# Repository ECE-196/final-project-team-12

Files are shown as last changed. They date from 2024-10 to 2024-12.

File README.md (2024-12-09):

We developed a device to assist drivers with parking, specifically in compact spots. This will be done with a LiDAR sensor that will map a 2D birds eye view of obstacles in front and to the side of the car. This map will then be displayed on a screen for the driver to see and make judgements accordingly while parking. The device will assist the driver to measure the dimensions of a parking spot and help judge whether or not it is too compact to park in. 

This repository contains all the files and progression pictures/videos used to develop this product.

See our [Website](https://sites.google.com/ucsd.edu/team-12?usp=sharing) for more information

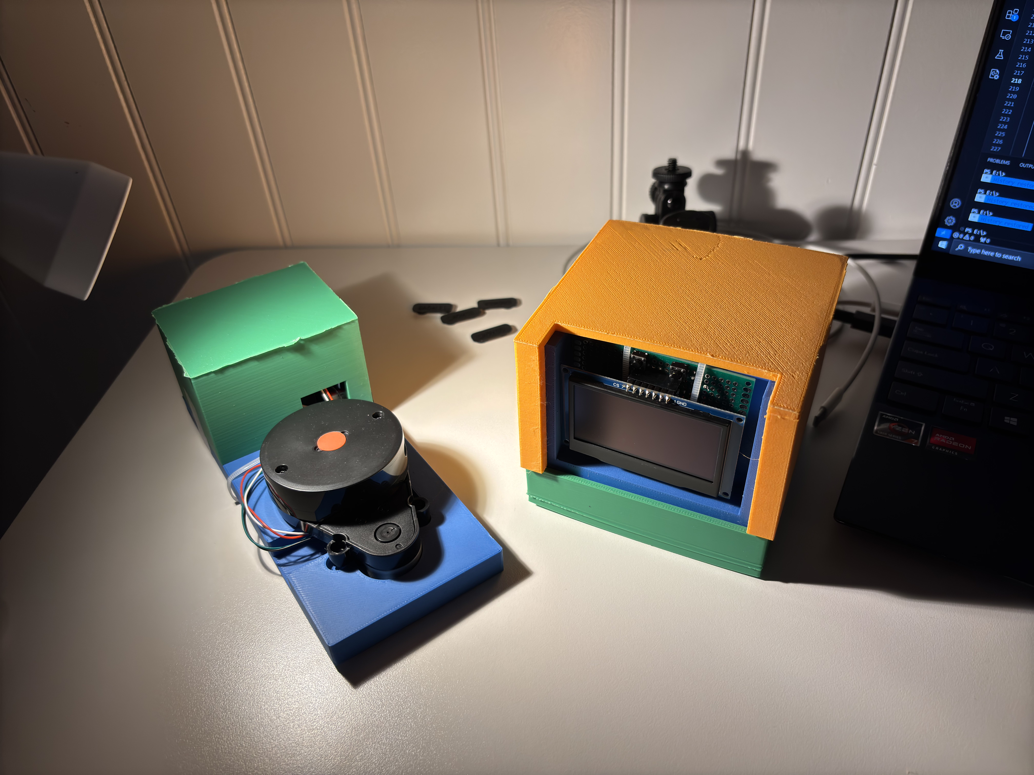
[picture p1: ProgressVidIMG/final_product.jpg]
final_product


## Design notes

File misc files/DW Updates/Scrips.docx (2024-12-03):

Did you ever find parking spaces are too small to comfortably park into? Do you consider yourself as a bad driver and would like some assistance to avoid hitting people’s car? Do you find it difficult to eye measure distances between obstacles and your car? Our parking assistance device is here to help you visualize obstacles near the front side of your car. Our product consists a lidar sensor scanning everything around your car front hood, displaying any obstacles on the screen. You will see how much space left your car has. No more accidentally hitting the car parked next to and having to worry about paying for the damage.

We designed our product to be as simple to install as possible. All you need to do is mount the sensor mount the sensor on your car using the suction cup (SPEECH PAUSE HERE A LITTLE), turn on the power switches, and set up the display. It just that easy! Our product allows for seamless wireless communication between devices, which means there's no need for cumbersome wires and hassles. Using LiDAR technology, it gives a 180 degree view of your car’s surroundings. This information is sent wirelessly to the screen. Surround cars, pillars, and other obstacles will now be detected and displayed to give you a better view of your surroundings. Gone are the days where parking is a hassle, gets your today for $499.99! Spot with our device, worry no more!

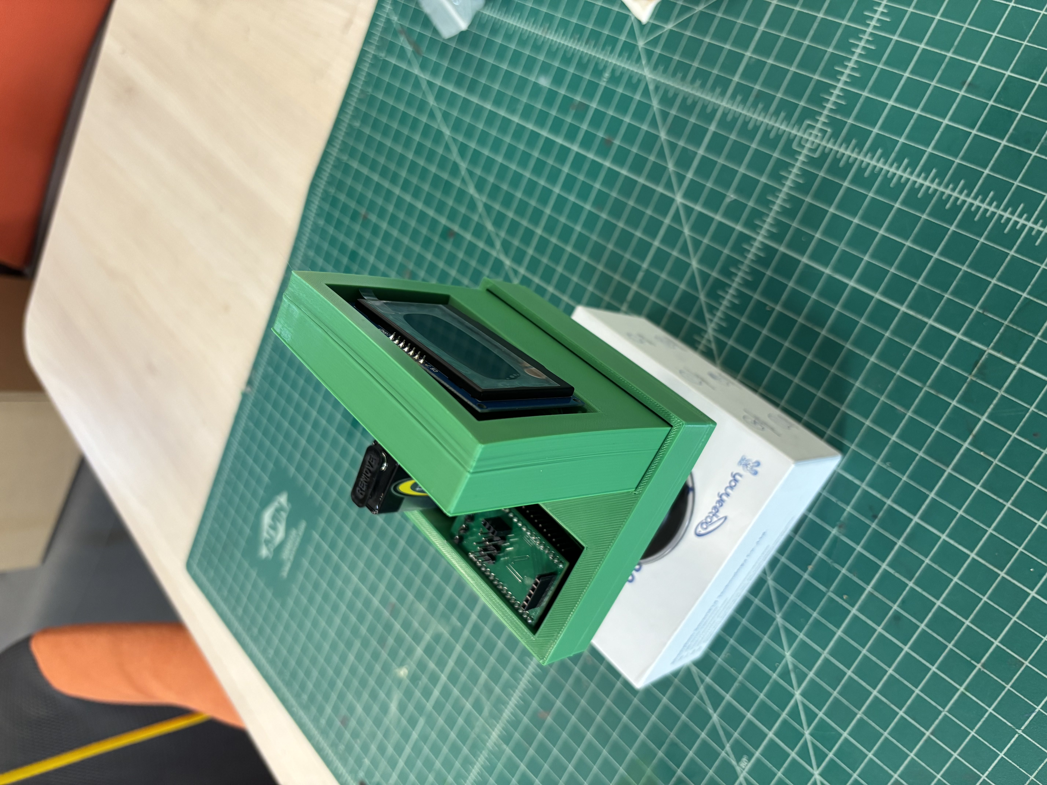
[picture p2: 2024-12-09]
ProgressVidIMG/prototype_screen_module.jpg

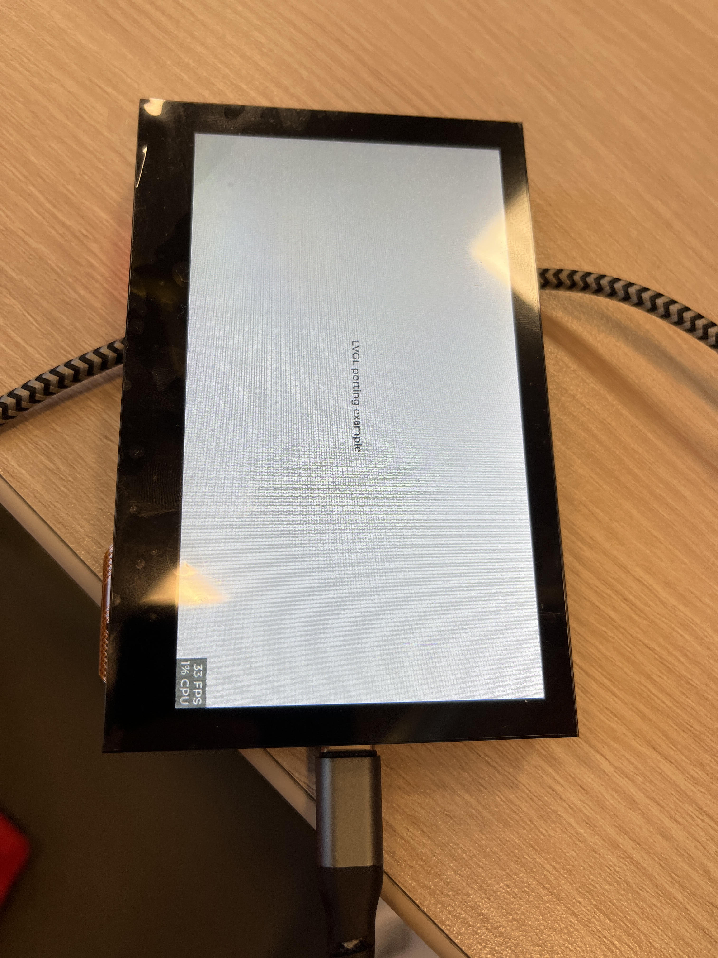
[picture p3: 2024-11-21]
misc files/DW Updates/ScreenDisplay.jpg

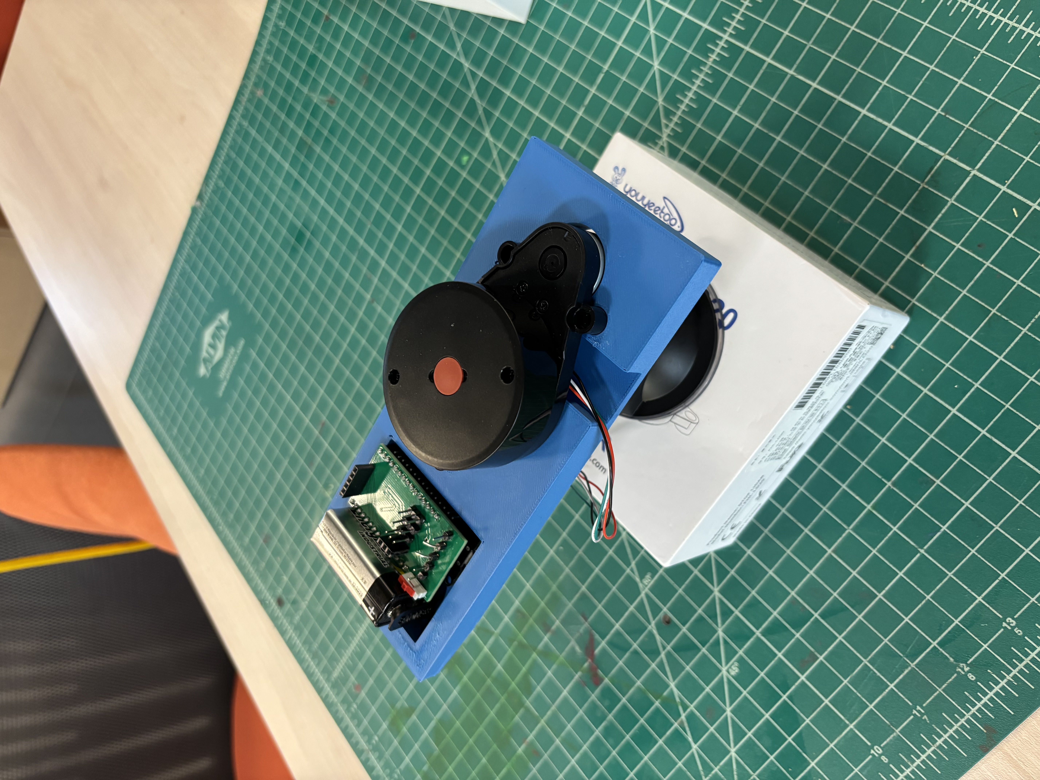
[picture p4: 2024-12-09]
ProgressVidIMG/prototype_sensor_module.jpg

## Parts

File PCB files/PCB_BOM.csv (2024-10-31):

Reference | Value | Datasheet | Footprint | Qty | DNP | Digikey part #
C1 | 22uF | ~ | Capacitor_SMD:C_0805_2012Metric | 1 |  | 1276-2909-1-ND
C2 | 100nF | ~ | Capacitor_SMD:C_0805_2012Metric | 1 |  | 1276-1782-1-ND
C3 | 10uF | ~ | Capacitor_SMD:C_0805_2012Metric | 1 |  | 1276-1096-1-ND
J1,J2 | Conn_01x15_Socket | ~ | Connector_PinHeader_2.54mm:PinHeader_1x15_P2.54mm_Vertical | 2 |  | S7013-ND
J3 | LiDAR_IN | ~ | Connector_PinHeader_2.54mm:PinHeader_1x03_P2.54mm_Vertical | 1 |  | S7001-ND
J4,J5,J6,J7,J12 | Conn_01x01_Pin | ~ | Connector_PinHeader_2.54mm:PinHeader_1x01_P2.54mm_Vertical | 5 |  | A26540-ND
J8,J9,J10 | Conn_01x03_Pin | ~ | Connector_PinHeader_2.54mm:PinHeader_1x03_P2.54mm_Vertical | 3 |  | 732-5316-ND
J11 | Conn_01x05_Pin | ~ | Connector_PinHeader_2.54mm:PinHeader_1x05_P2.54mm_Vertical | 1 |  | 732-5318-ND
L1 | 3.3uH | ~ | Inductor_SMD:L_0805_2012Metric | 1 |  | 2035-1251-1-ND
R1 | 52.3k | ~ | Resistor_SMD:R_0805_2012Metric | 1 |  | 541-52.3KCCT-ND
R2 | 10k | ~ | Resistor_SMD:R_0805_2012Metric | 1 |  | RR12P10.0KDCT-ND
SW1 | sw1 |  | 09.03201.02 | 1 |  | 1948-1086-ND
U1 | AP62150Z6-7 | AP62150Z6-7 | KiCADv6:SOT563_DIO | 1 |  | 31-AP62150Z6-7CT-ND

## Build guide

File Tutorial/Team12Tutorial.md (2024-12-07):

---
title: UART Communication
date: 12/6/2024
authors:
  - name: Cleavant Yang
  - name: Danny Wu
  - name: Aria Mottaghi
---
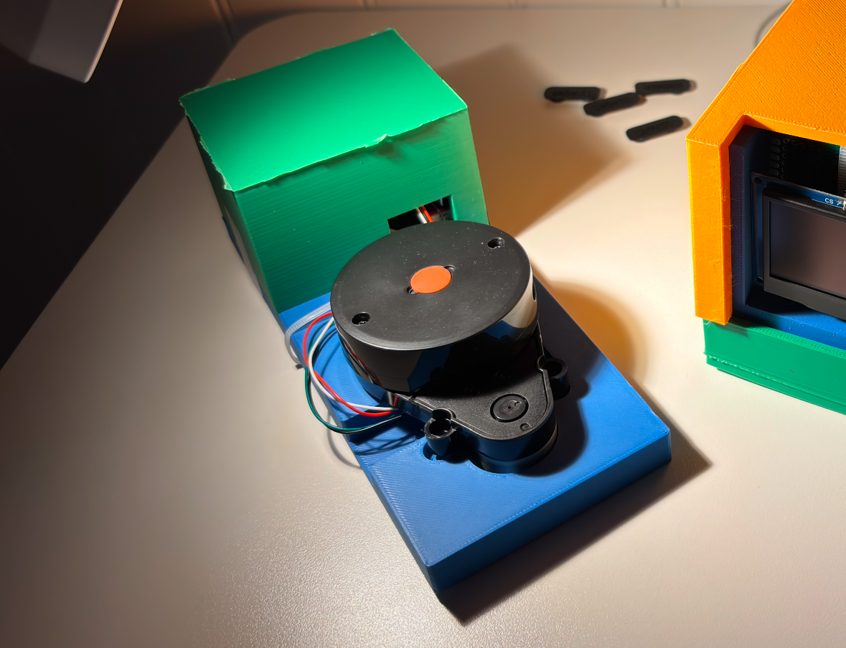
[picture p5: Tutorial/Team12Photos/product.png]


## Introduction

This tutorial will go over how to read incoming UART data from any device using CircuitPython. This is useful as a lot of devices send and receive information through this communication protocol. For the purposes of this tutorial, we will be receiving and decoding data from an [LD-14P LiDAR sensor][Lidar Link].  

### Learning Objectives

- UART Communication Protocol
- Circuit Python
- Datasheet Comprehension

## Background Information

Serial communication is a common method used in a lot of devices and electronics to send and receive information. Plenty of communication protocols exist such as I2C, SPI, and UART. Understanding serial communication, particularly UART (Universal Asynchronous Receiver-Transmitter), is essential for controlling, interfacing, and interacting with a wide range of devices, which is essential for projects that involve embedded systems. 

Pros:
- Overall simplicity
- Versatility

Cons:
- Slower speeds compared to other protocols
- Limited range as signal quality degrades over long distances

## Tools and Components Needed
- Computer or laptop that can run VSCode
- Visual Studio Code, download it [here][VSCode Link]
- Circuit Python, you can follow this instruction [here][Circuit Python Link], which is the same instruction for your VU Meter
- youyeetoo FHL-LD20 8 Meters 360 deg Lidar Sensor, you can find it [here][Lidar Link] and its datasheet [here][datasheetLink]
- ESP32 Devboard (The same one you made in class), details are found [here][devboardLink]
- USB-C cable
- Wires

## Get Started

### Serial Protocol

The UART communication protocol transmits data by sending bits one at a time, represented by high or low voltage levels, to the receiving device. Before communication begins, both devices agree on a baud rate, which determines the speed at which bits are transmitted per second.

Baudrates are going to vary widely across devices so it's important to make sure you are using the correct one. This information should always be outlined in the datasheet of the device you are working with (more on this below).

### Datasheet

Whenever working with electronic devices, it's essential to consult the accompanying datasheet, which provides detailed information on how the device works and how to configure it for your needs. The datasheet for the LiDAR sensor we're using can be found [here][datasheetLink].

In the case of the LiDAR sensor, the [datasheet][datasheetLink], when describing "transmission parameters," specifies a baud rate of 230400, meaning that 230,400 bits are transmitted per second.

### LiDAR Sensor

Since we're using a LiDAR sensor in this example, it's important to understand how it works. LiDAR operates by emitting a laser beam, which is invisible to the naked eye, towards nearby objects. The light reflects off these objects and is then received back by the LiDAR sensor. By knowing the speed of light and measuring the time it takes for the laser to travel to the object and return, the sensor can accurately calculate the distance to nearby objects. This distance data is then processed and continuously transmitted via the TX line as UART data.

This operation happens several thousands of times per second all while the internal sensors themselves are rotating in circles. This allows for a 2D top down mapping of all nearby objects

### ESP32

We will be using the [ESP32 devboard][devboardLink] you should have already made in class. This will be the microcontoller used to receive and process the UART data that's emitting from the LiDAR sensor.

### CircuitPython

I assume you have built the VU Meter using Circuit Python as [this instruction][Circuit Python Link], so you should have it installed and set up for the devboard you built earlier in class.

We will be using CircuitPython with this specific ESP32 chip as the preinstalled libraries are able to handle higher baudrates.

## Part 1: Wiring

### Introduction

We are first going to wire the LiDAR sensor to the devboard to interface with it.

### Objective

- Understanding the physical hardware of the sensor
- Learn how to read and comprehend information from a datasheet

### Background Information

The LiDAR sensor has four wires, each serving a different purpose. The datasheet specifies which wire corresponds to which function, and includes the following diagram for reference:

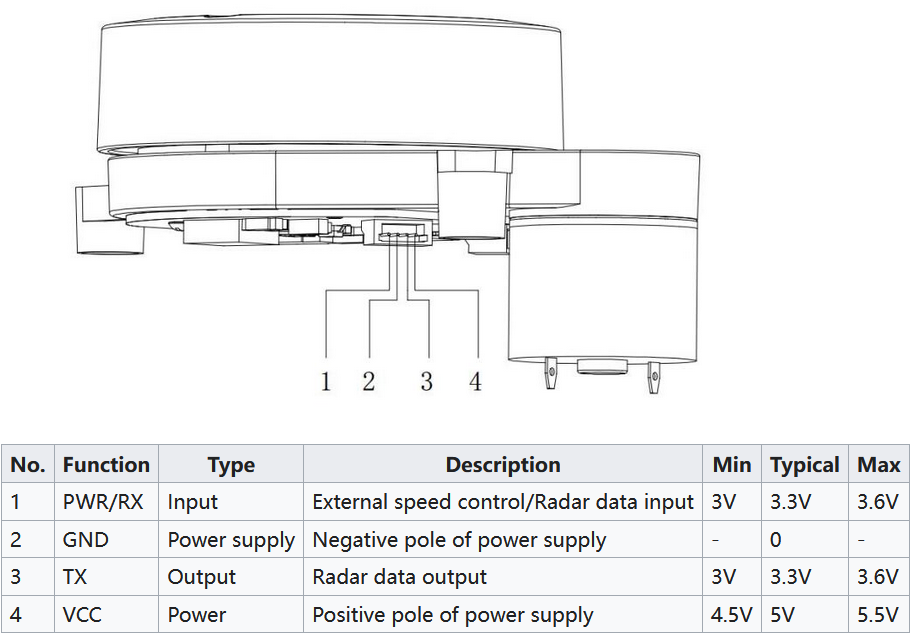
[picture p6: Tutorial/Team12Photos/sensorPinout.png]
pinoutPhoto


Because we are only interested in receiving UART data, further reading into the datasheet reveals that we can safely ignore the "PWR/RX" pin as there will be no need to send information to the sensor. We only care about pins 2, 3, and 4.

### Components

- LiDAR sensor
- 3 Wires
- Devboard

### Instructional

All the pins coming out of the sensor are going to be directly wired to the devboard. Referring back to the pinout image above, we need to power the VCC pin with 5V, tie the GND pin to the same ground as the devboard, and **connect the TX pin of the sensor to the RX0 of the devboard**. This wire will contain all the crucial data that will be read by the ESP32

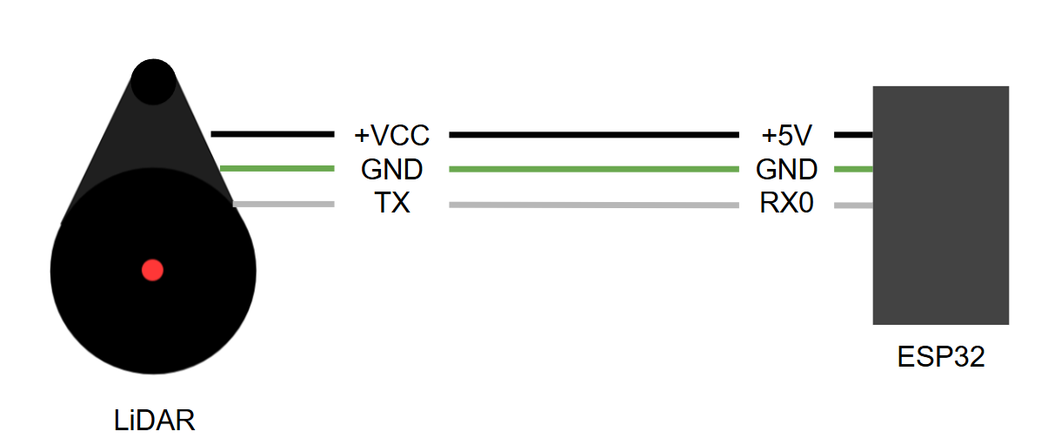
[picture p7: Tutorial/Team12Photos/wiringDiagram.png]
wiringDiagram


## Part 2: Code

### Introduction

We are now going to write code to interface with the LiDAR sensor in CircuitPython

### Objective

- Understand how to interface with UART data in CircuitPython
- Learn how to read and comprehend information from a datasheet

### Background Information

This section assumes you have a basic understanding of python syntax and that CircuitPython is already installed on your devboard.

### Components

- Devboard
- USB-C cable
- Computer/Laptop

### Instructional

Import the following libraries to interact with the devboard
```python
import board
import busio
```

Create a UART instance from the `busio.UART` class. Assign `baudrate` to 230400
```python
uart = busio.UART(board.TX, board.RX, baudrate=230400, timeout=0.1)
```

Print the incoming data coming from the UART instance. 
```python
while True:
    if uart.in_waiting > 0:
        data = uart.read()
        print(f"Received data: {data}")
```

This piece of code waits for data to be sent to the `RX0` pin and prints it to the console.

The LiDAR should be spinning and transmitting data automatically when powered. You should see something as such:
```
Received data: b'\x54'
Received data: b'\x2C'
Received data: b'\x68'
Received data: b'\x08'
.
.
.
```
We are now successfully receiving the UART LiDAR sensor data in [hexadecimal format][hexWiki]. To understand what any of it means, we have to yet again refer back to the datasheet. 

They specify the data structure of the packet they are sending out under "Data Packet Format"
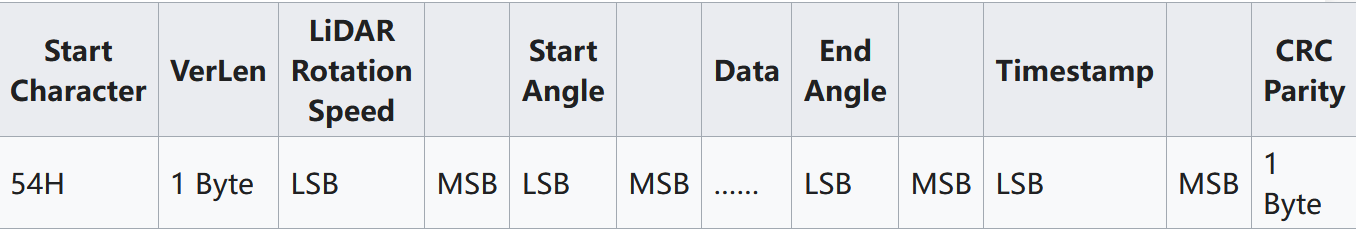
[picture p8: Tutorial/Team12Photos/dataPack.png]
dataPacket

Information on what MSB and LSB mean can be found [here][MLSB]

They also provide an example output and the corresponding decoded information:
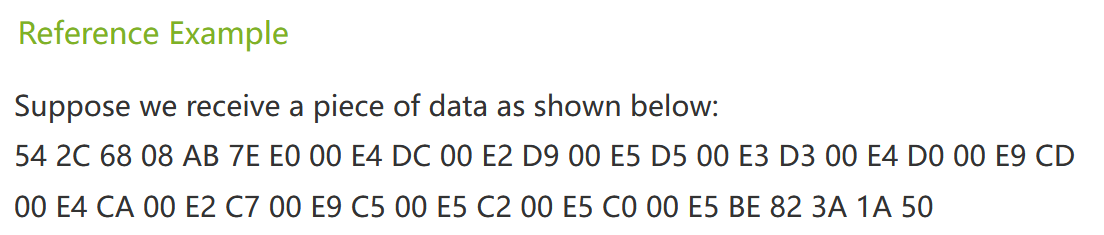
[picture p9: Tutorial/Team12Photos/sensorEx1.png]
inputExample1

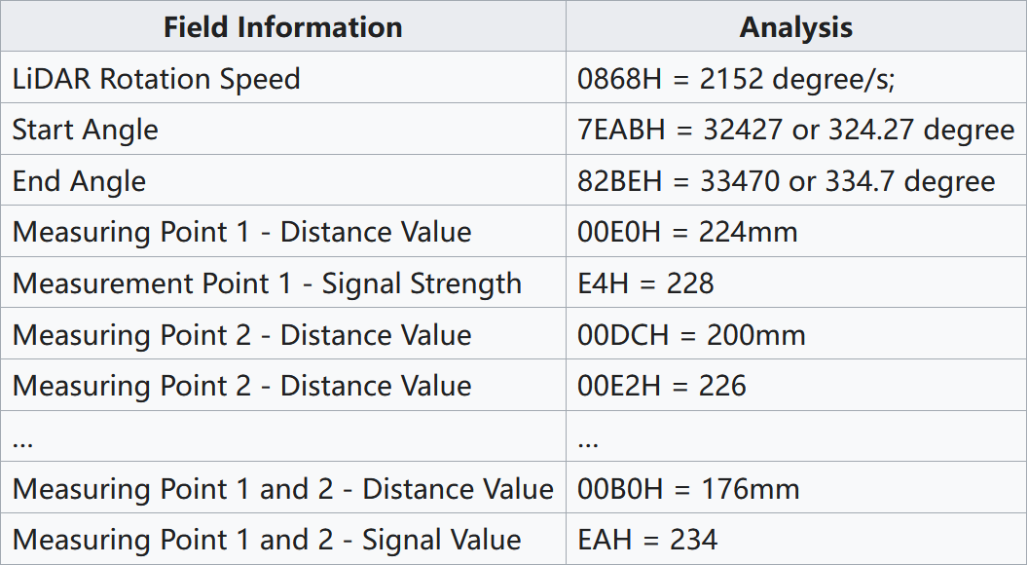
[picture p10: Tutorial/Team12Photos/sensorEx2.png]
inputExample2


## Example

### Introduction

We have successfully grabbed the UART data that was being transmitted by a sensor. Now we can convert the raw bytes that are being received to readable information of what the LiDAR is seeing.

### Example
The datasheet specifies that each set (or "packet") of data contains 47 bytes which all start with `0x54` indicating the beginning of the packet. We can first create a list that will hold all the information each packet contains
```python
packet_size = 47
packet = []
```

Now we want to take each byte we're receiving and place it into the list
```python
while True:
    if uart.in_waiting > 0:
        data = uart.read(uart.in_waiting)
        packet.extend(data)
```

We now implement another `while` loop which is responsible for processing the incoming data once we have enough bytes to form a full packet (in this case, 47 bytes).
```python
        while len(packet) >= packet_size:
            current_packet = packet[:packet_size]
            packet = packet[packet_size:]
```
The code slices the first 47 bytes from the `packet` list and stores them in `current_packet`. `current_packet` now holds one full packet that we will process. 

After extracting the first 47 bytes into `current_packet`, we update the `packet` list to remove those 47 bytes

This ensures that the remaining data in the `packet` list, if any, stays for the next loop cycle to be processed later.

Now we essentially "shift" what 47 bytes is contained in `current_packet` until the first byte is the start byte `0x54`
```python
            if current_packet[0] == 0x54:
                .
                .
                .
                # packet operations here

            else:
                packet = packet[1:]
```
Inside the conditional is code that executes with the guarantee that `current_packet` is a properly formatted data packet transmitted from the LiDAR

Refering back to this image:
dataPacket
We now know what information is contained in each index

We can do some basic print statements to verify that our code works as intended and that we're receiving the information correctly
```python
            if current_packet[0] == 0x54:
                for byte in current_packet:
                    print(f"{byte:02X}", end=" ")
                print()
            else:
                packet = packet[1:]
```

This is what was printed running the code above. Notice how similar it looks to the example given in the datasheet:
```
54 2C 74 08 B0 86 00 00 D4 00 00 D4 00 00 D4 00 00 D4 00 00 D4 00 00 D5 00 00 D5 00 00 49 00 00 5F 00 00 B0 00 00 D2 00 00 D4 02 89 1E 09 1F
54 2C 68 08 AB 7E E0 00 E4 DC 00 E2 D9 00 E5 D5 00 E3 D3 00 E4 D0 00 E9 CD 00 E4 CA 00 E2 C7 00 E9 C5 00 E5 C2 00 E5 C0 00 E5 BE 82 3A 1A 50
.
.
.
```

Given that we know each index's and the information it contains, here is an example function that prints legible information coming from the sensor:
```python
            if current_packet[0] == 0x54:
                print("radar speed:", end = " ")
                print(curPack[3]*256 + curPack[2])

                print("start angle:", end = " ")
                print(curPack[5]*256 + curPack[4])
                print("end angle:  ", end = " ")
                print(curPack[43]*256 + curPack[42])

                print("time:", end = " ")
                print(curPack[45]*256 + curPack[44])
            else:
                packet = packet[1:]
```

### Analysis

Explain how the example used your tutorial topic. Give in-depth analysis of each part and show your understanding of the tutorial topic

This example demonstrates how to decode each UART packet coming from a LiDAR sensor and, with the datasheet in hand, we can convert the bytes into legible information useful for interpreting the sensor's measurements. Using the data coming into the RX0 pin and knowing how it's formatted, we can extract meaningful data such as radar speed, angles, and other environmental details.

## Additional Resources

### Useful links

[Bit Significance][MLSB]

[Hexadecimal][hexWiki]

[LiDAR Sensor][Lidar Link]

[LiDAR Datasheet][datasheetLink]

[Lidar Link]: https://www.amazon.com/youyeetoo-FHL-LD20-Raspberry-Triangulated-Start-Stop/dp/B0C3CX17FN
[ESP32 Link]: https://www.amazon.com/dp/B08D5ZD528?ref=ppx_yo2ov_dt_b_fed_asin_title&th=1
[Screen Link]: https://www.amazon.com/dp/B0D7HN3XQ5?ref=ppx_yo2ov_dt_b_fed_asin_title
[Suction Cup Link]: https://www.amazon.com/ThtRht-Suction-Windshield-Camcorder-Recorder/dp/B0CPLV4B9F
[ESP-NOW Link]: https://www.espressif.com/en/solutions/low-power-solutions/esp-now
[Arduino IDE Link]: https://www.arduino.cc/en/software
[VSCode Link]: https://code.visualstudio.com/
[Circuit Python Link]: https://ece-196.github.io/docs/assignments/vu-meter/firmware/
[OLED Screen Link]: https://www.amazon.com/Teyleten-Robot-Display-SSD1309-Interface/dp/B09LND6QJ1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
[Library Link]: https://circuitpython.org/libraries
[SPI Wiki Link]: https://en.wikipedia.org/wiki/Serial_Peripheral_Interface
[datasheetLink]: https://www.waveshare.com/wiki/D200_LiDAR_Kit
[devboardLink]: https://ece-196.github.io/docs/assignments/dev-board/
[hexWiki]: https://en.wikipedia.org/wiki/Hexadecimal
[MLSB]: https://en.wikipedia.org/wiki/Bit_numbering

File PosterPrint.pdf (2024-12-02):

# Parking Assistant

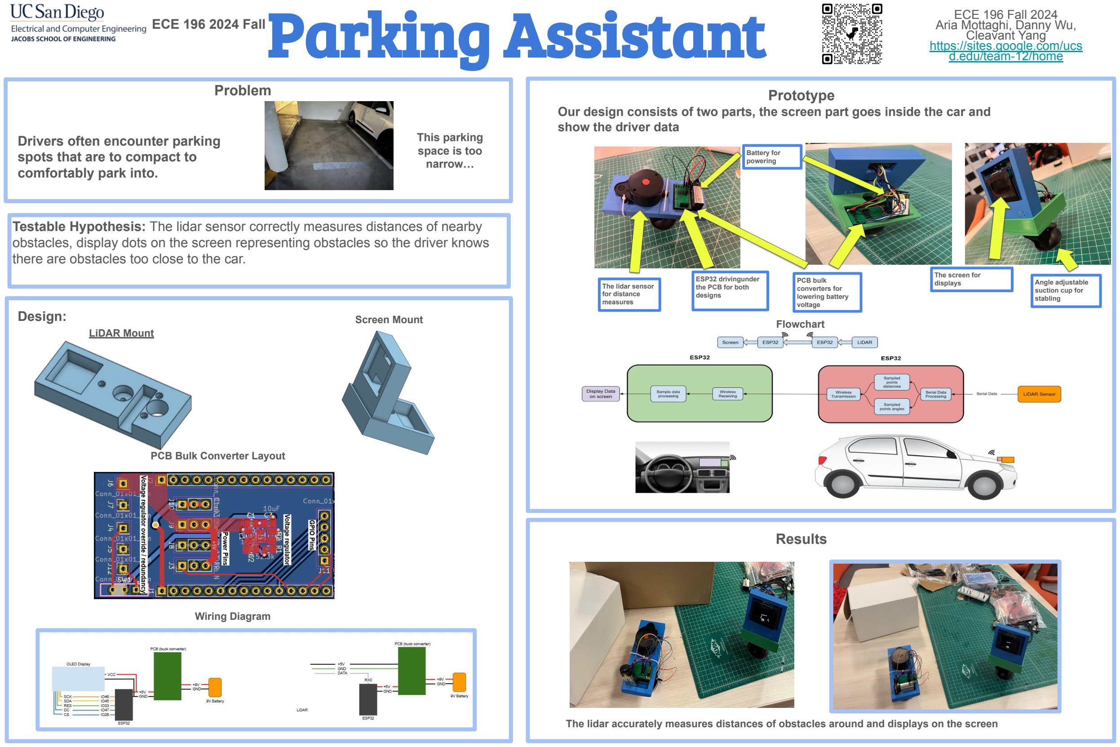
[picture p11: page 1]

ECE 196 Fall 2024
Aria Mottaghi, Danny Wu,
Cleavant Yang
https://sites.google.com/ucsd.edu/team-12/home (https://sites.google.com/ucsd.edu/team-12/home)

Drivers often encounter parking spots that are to compact to comfortably park into.

Testable Hypothesis: The lidar sensor correctly measures distances of nearby obstacles, display dots on the screen representing obstacles so the driver knows there are obstacles too close to the car.

Prototype

This parking
space is too
narrow…

Battery for
powering

LiDAR Mount

Angle adjustable
suction cup for
stabling

The screen for
displays

Our design consists of two parts, the screen part goes inside the car and show the driver data

PCB bulk
converters for
lowering battery
voltage
Design:

PCB Bulk Converter Layout

Wiring Diagram

Screen Mount

ECE 196 2024 Fall

The lidar sensor
for distance
measures

ESP32 drivingunder
the PCB for both
designs

Problem

Results

The lidar accurately measures distances of obstacles around and displays on the screen

Flowchart

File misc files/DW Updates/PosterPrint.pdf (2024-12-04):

# Parking Assistant

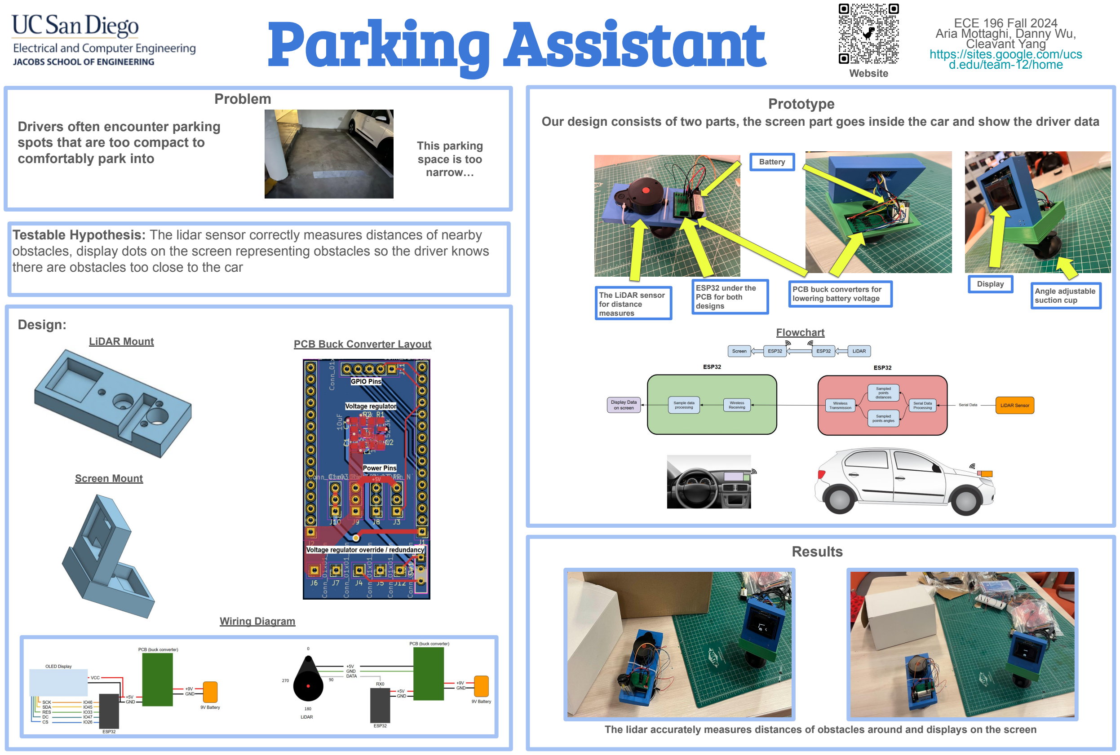
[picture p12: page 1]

ECE 196 Fall 2024
Aria Mottaghi, Danny Wu,
Cleavant Yang
https://sites.google.com/ucsd.edu/team-12/home (https://sites.google.com/ucsd.edu/team-12/home)

Drivers often encounter parking spots that are too compact to comfortably park into

Testable Hypothesis: The lidar sensor correctly measures distances of nearby obstacles, display dots on the screen representing obstacles so the driver knows there are obstacles too close to the car

Prototype

This parking
space is too
narrow…

Battery

LiDAR Mount

Angle adjustable
suction cup

Display

Our design consists of two parts, the screen part goes inside the car and show the driver data

PCB buck converters for
lowering battery voltage

Design:

PCB Buck Converter Layout

Wiring Diagram

Screen Mount

Website

The LiDAR sensor
for distance
measures

ESP32 under the
PCB for both
designs

Problem

Results

The lidar accurately measures distances of obstacles around and displays on the screen

Flowchart

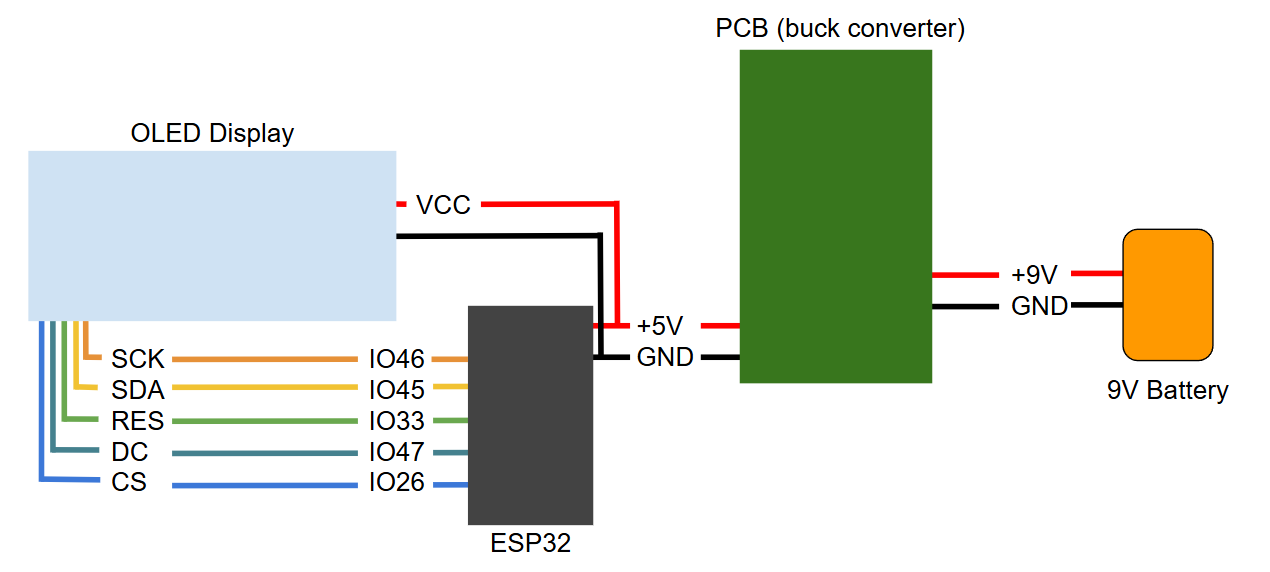
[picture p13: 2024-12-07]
ProgressVidIMG/wiringDiagram192p1.png

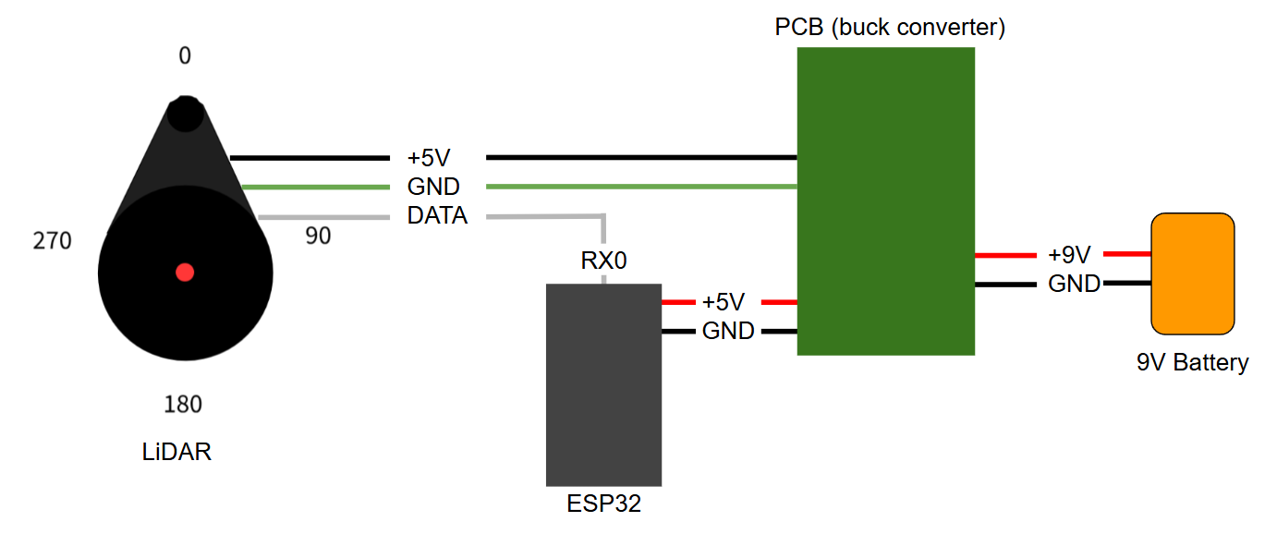
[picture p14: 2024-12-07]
ProgressVidIMG/wiringDiagram192p2.png

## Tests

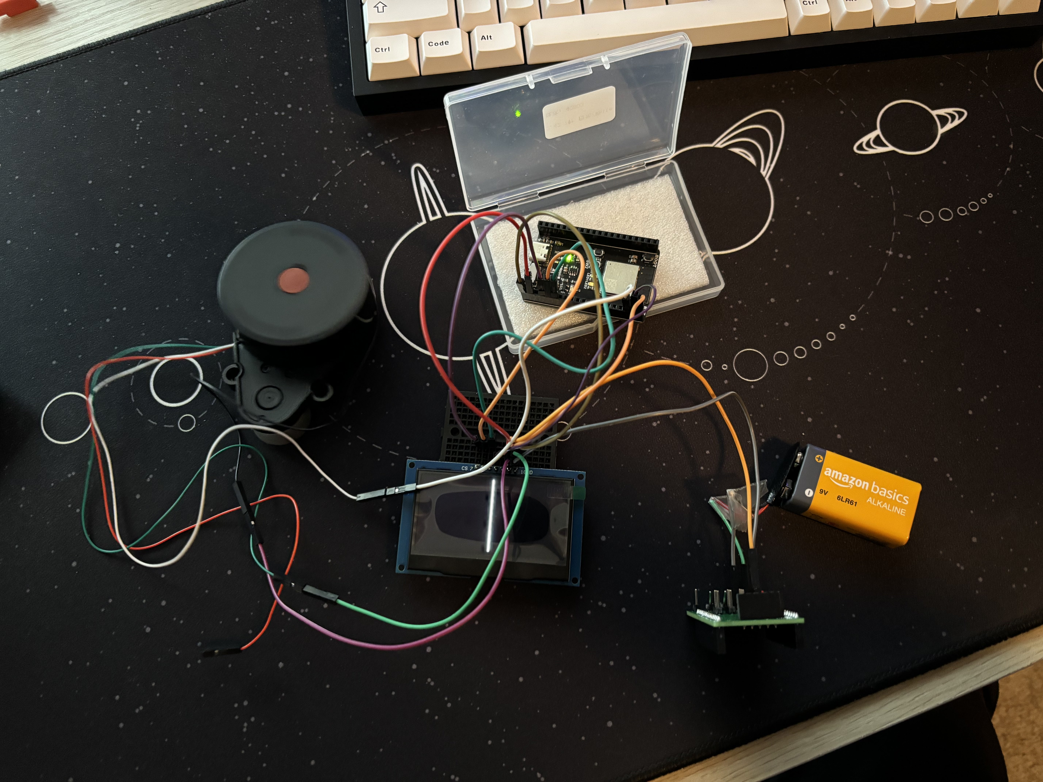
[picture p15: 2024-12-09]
ProgressVidIMG/first_system_integration_test.jpg

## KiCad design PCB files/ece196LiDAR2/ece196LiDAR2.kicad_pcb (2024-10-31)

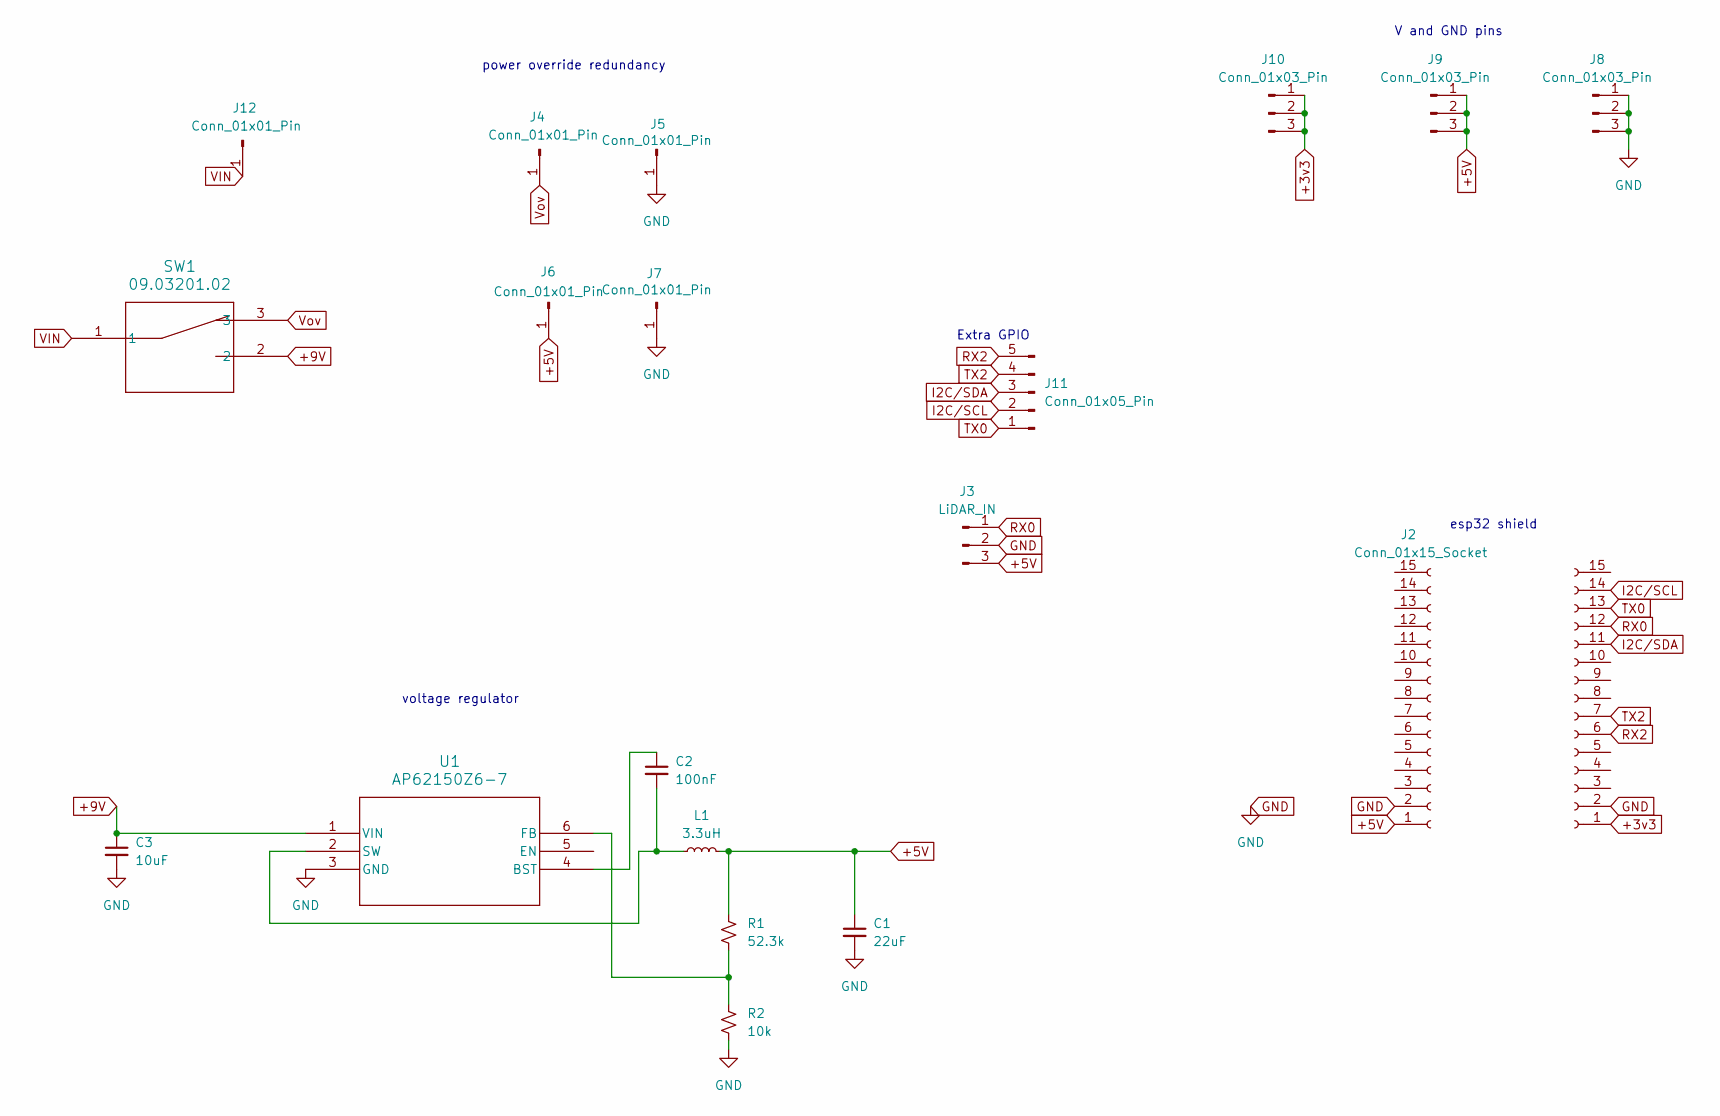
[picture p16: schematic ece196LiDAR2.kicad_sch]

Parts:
C1: 22uF; C_0805_2012Metric
C2: 100nF; C_0805_2012Metric
C3: 10uF; C_0805_2012Metric
J1, J2: Conn_01x15_Socket; PinHeader_1x15_P2.54mm_Vertical
J3: LiDAR_IN; PinHeader_1x03_P2.54mm_Vertical
J4, J5, J6, J7, J12: Conn_01x01_Pin; PinHeader_1x01_P2.54mm_Vertical
J8, J9, J10: Conn_01x03_Pin; PinHeader_1x03_P2.54mm_Vertical
J11: Conn_01x05_Pin; PinHeader_1x05_P2.54mm_Vertical
L1: 3.3uH; L_0805_2012Metric
R1: 52.3k; R_0805_2012Metric
R2: 10k; R_0805_2012Metric
SW1: 09.03201.02; 09.03201_EAO
U1: AP62150Z6-7; SOT563_DIO

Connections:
+3v3: J1.1, J10.1, J10.2, J10.3
+5V: C1.1, J2.1, J3.3, J6.1, J9.1, J9.2, J9.3, L1.2, R1.1
+9V: C3.1, SW1.2, U1.1 (VIN)
GND: C1.2, C3.2, J1.2, J2.2, J3.2, J5.1, J7.1, J8.1, J8.2, J8.3, R2.2, U1.3 (GND)
I2C/SCL: J1.14, J11.2
I2C/SDA: J1.11, J11.3
unnamed: C2.1, U1.4 (BST)
unnamed: R1.2, R2.1, U1.6 (FB)
unnamed: C2.2, L1.1, U1.2 (SW)
RX0: J1.12, J3.1
RX2: J1.6, J11.5
TX0: J1.13, J11.1
TX2: J1.7, J11.4
VIN: J12.1, SW1.1
Vov: J4.1, SW1.3

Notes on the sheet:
voltage regulator
Extra GPIO
V and GND pins
esp32 shield
power override redundancy

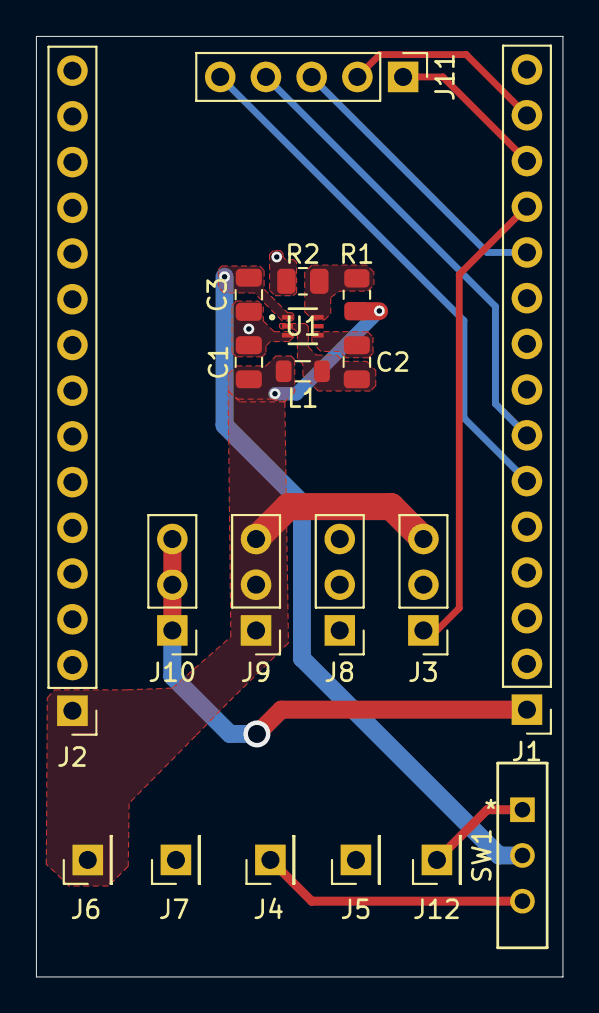
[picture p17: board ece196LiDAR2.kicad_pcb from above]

Board: 2 copper layers, 29.2 x 52.2 mm, 20 parts (0 on the bottom side), 15 nets.

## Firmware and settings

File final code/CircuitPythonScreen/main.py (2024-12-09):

import board
import time
import random
import displayio
import adafruit_displayio_ssd1306
import busio
import espnow #type: ignore
import math
import json
from digitalio import DigitalInOut, Direction

'''
displayio.release_displays() #release pins

WIDTH = 128
HEIGHT = 64
BORDER = 5

# Set up the SPI or I2C connection (depending on your setup)
cs = board.IO26 #IO26, chip select
dc = board.IO47 #IO47, data address
reset = board.IO33 #IO33, reset pin
spi = busio.SPI(board.IO46, MOSI=board.IO45) #initialize bus
display_bus = displayio.FourWire(spi, command=dc, chip_select=cs,
                                 reset=reset, baudrate=1000000)
#SDA IO45, MOSI
#SCK IO46, clock

# Create the display object
display = adafruit_displayio_ssd1306.SSD1306(display_bus, width=WIDTH, height=HEIGHT)

splash = displayio.Group() #Manage a group of sprites and groups and how they are inter-related.
display.show(splash)

# Create a bitmap where we can draw pixels
bitmap = displayio.Bitmap(128, 64, 2)  # 128x64 pixels, 2 colors (black and white)
palette = displayio.Palette(2)
palette[0] = 0x000000  # Black
palette[1] = 0xFFFFFF  # White

# Create a TileGrid to hold the bitmap
tile_grid = displayio.TileGrid(bitmap, pixel_shader=palette)

# Create a Group and add the TileGrid to it
group = displayio.Group()
group.append(tile_grid) # append() adds elements to splash and make them visible

# Show the group on the display
display.show(group)

# Function to draw a single pixel
def draw_pixel(x, y, color):
    if 0 <= x < 128 and 0 <= y < 64:  # Make sure the pixel is within bounds
        bitmap[x, y] = color
        time.sleep(0.1)
        #bitmap[x, y] = 0 #turn off pixel

def turnoff_pixel(x, y, color):
    if 0 <= x < 128 and 0 <= y < 64:  # Make sure the pixel is within bounds
        bitmap[x, y] = 0
        # time.sleep(0.2)
        # bitmap[x, y] = 0 #turn off pixel

# Draw some test pixels
#draw_pixel(random.randint(0,128), random.randint(0,64), 1)  # Draw a white pixel at (10, 10)

# To update display, we don’t need anything else because displayio handles it automatically
while True:
    for x in range(128):
        draw_pixel(x, 0, 1)  # Draw a white pixel at (10, 10)
        #time.sleep(0.1)
    for x in range(128):
        turnoff_pixel(x,0,0)
    #draw_pixel(random.randint(0,128), random.randint(0,64), 1)  # Draw a white pixel at (10, 10)
    time.sleep(0.1)
'''

# =============================================================================================================================
# display initialization 

refreshRate = 3
scaleDown = 10 # variable to adjust to zoom in or out on the screen
scdl = 10
scdm = 25
scdh = 100
leftButton = DigitalInOut(board.IO1)
leftButton.direction = Direction.INPUT
rightButton = DigitalInOut(board.IO2)
rightButton.direction = Direction.INPUT
pLeftButton = False
pRightButton = False

displayio.release_displays() #release pins

# Set up the SPI or I2C connection (depending on your setup)
cs = board.IO26 #IO26
dc = board.IO47 #IO47
reset = board.IO33 #IO33
spi = busio.SPI(board.IO46, MOSI=board.IO45) #initialize bus
display_bus = displayio.FourWire(spi, command=dc, chip_select=cs, reset=reset, baudrate=230400) # 1000000
#SDA IO45
#SCK IO46

# Create the display object
display = adafruit_displayio_ssd1306.SSD1306(display_bus, width=128, height=64)

splash = displayio.Group() #Manage a group of sprites and groups and how they are inter-related.
display.show(splash)

# Create a bitmap where we can draw pixels
bitmap = displayio.Bitmap(128, 64, 2)  # 128x64 pixels, 2 colors (black and white)
palette = displayio.Palette(2)
palette[0] = 0x000000  # Black
palette[1] = 0xFFFFFF  # White

# Create a TileGrid to hold the bitmap
tile_grid = displayio.TileGrid(bitmap, pixel_shader=palette)

# Create a Group and add the TileGrid to it
group = displayio.Group()
group.append(tile_grid) # append() adds elements to splash and make them visible

# Show the group on the display 
display.show(group)

def drawPixel(x, y, z):
    if 0 <= x < 128 and 0 <= y < 64:  # will only draw pixels within bounds
        if bitmap[x,y] != int(z):
            bitmap[x, y] = int(z)

def drawCar():
    global scaleDown
    carPixels = set()
    height = 58 # y coord 

# real distance in mm / scaleDown = pixelPlot
# 8000/10 = 800 (too far at this scaleDown value)
# 8000/x = 440 (find x for it to be at the midpoint) (x = 18.18)
# 8000/100 = 80 ( < 127, will fit on screen)

# 2000/10 = 200
# 2000/18.18 = 110
# 2000/100 = 20

# 1000/10 = 100 
# 1000/18.18 = 55
# 1000/100 = 10 

    if scaleDown == scdh:
        for i in range(57,69): # bumper width
            carPixels.add((i,height)) # bumper height
        for i in range(height + 1,64): # left side height
            carPixels.add((56,i)) # left side x coord
        for i in range(height + 1,64): # right side height
            carPixels.add((69,i)) # right side x coord

    elif scaleDown == scdm:
        # 28
        carPixels.add((28,height+5))
        carPixels.add((29,height+4))
        carPixels.add((29,height+3))
        for i in range(30,32):
            carPixels.add((i,height+2)) 
        for i in range(32,50):
            carPixels.add((i,height+1)) 
        for i in range(50,77): # bumper width
            carPixels.add((i,height)) # bumper height
        for i in range(77,95): # bumper width
            carPixels.add((i,height+1)) # bumper height
        for i in range(95,97):
            carPixels.add((i,height+2))
        carPixels.add((97,height+3))
        carPixels.add((97,height+4))
        carPixels.add((98,height+5))
        
    elif scaleDown == scdl:
        for i in range(57,69): # bumper width
            carPixels.add((i,height)) # bumper height
        for i in range(height + 1,64): # left side height
            carPixels.add((56,i)) # left side x coord
        for i in range(height + 1,64): # right side height
            carPixels.add((69,i)) # right side x coord
        for i in range(59,67):
            carPixels.add((i,63))

        # carPixels.add((63,height+5))
        # 98

    for x in carPixels:
        bitmap[x] = 1
drawCar()
# 0 - 57 is the y range because the car bumper goes to y = 58 - 63

def clearScreen():
    global timeSinceReset
    bitmap.fill(0)
    drawCar()
    timeSinceReset = time.monotonic()

timeSinceReset = time.monotonic()

# Function to update plot based on angle and distance
def updatePlot(i):
    curTime = time.monotonic()
    global timeSinceReset, scaleDown
    
    if (27000 <= i[1] <= 36000) or (0 <= i[1] <= 9000):
        # Get the angle and distance from the data
        angle = ( 9000 - i[1]) / 100.0  # Convert angle from scaled value (e.g., 9000 = 90Â°) to degrees
        distance = i[0]  # Distance value
        
        # Convert angle to radians (since math functions use radians)
        angle_radians = math.radians(angle)

        # Center of the screen
        xMid = 63
        yMid = 59  # center the LiDAR to the car on the screen

        # polar to cartesian conversion
        x = xMid + int(distance * math.cos(angle_radians) / scaleDown)
        y = yMid - int(distance * math.sin(angle_radians) / scaleDown)  # Invert Y-axis



        drawPixel(x,y,1)  # Run the expression for each (x, y) pair
        if (curTime - timeSinceReset >= refreshRate):
            clearScreen()
#-------------------------------------------------------------------------
#Receiver Wireless Code Start
#import espnow, time

e = espnow.ESPNow()
packets = []
print("Initializing ESP-NOW Receiver...")
while True:
    # Read any incoming message
    if e:
        message = e.read()
        #print(type(message))
        #print("Received message:", message.msg)
        decoded_data = message.msg.decode('utf-8')  # Decode from bytes to string
        original_element = json.loads(decoded_data)  # Deserialize the JSON string back to the original element
        if isinstance(original_element,list) and original_element[0] != 0 and original_element[1] != 0:
            updatePlot(original_element)


        # more efficient but too volatile
        # # print(original_element)
        # if isinstance(original_element,str) and len(original_element) == 120:
        #     # print(original_element) 
        #     for i in range(0, len(original_element), 10):
        #         num1 = int(original_element[i:i+5])
        #         num2 = int(original_element[i+5:i+10])
        #         updatePlot([num1, num2])


    # Add a small delay to avoid overwhelming the loop
    time.sleep(0.001)  # Adjust sleep time as needed
    if leftButton.value == False and pLeftButton == True: # scaleDown go up
        if scaleDown == scdl:
            scaleDown = scdm
        elif scaleDown == scdm:
            scaleDown = scdh
        clearScreen()
    if rightButton.value == False and pRightButton == True: # scaleDown go down 
        if scaleDown == scdm:
            scaleDown = scdl
        elif scaleDown == scdh:
            scaleDown = scdm
        clearScreen()
    pLeftButton = leftButton.value
    pRightButton = rightButton.value

#Receiver Wireless Code Ends
#-------------------------------------------------------------------------

'''
import board
import time
import random
import displayio
import adafruit_displayio_ssd1306
import busio
import espnow #type: ignore
import math
import json
from digitalio import DigitalInOut, Direction

# =============================================================================================================================
# display initialization 

refreshRate = 3
scaleDown = 10 # variable to adjust to zoom in or out on the screen
scdl = 10
scdm = 25
scdh = 100
leftButton = DigitalInOut(board.D2)
leftButton.direction = Direction.INPUT
rightButton = DigitalInOut(board.D4)
rightButton.direction = Direction.INPUT
pLeftButton = False
pRightButton = False

displayio.release_displays() #release pins

# Set up the SPI or I2C connection (depending on your setup)
cs = board.D26 #IO26
dc = board.D27 #IO47
reset = board.D14 #IO33
spi = busio.SPI(board.D13, MOSI=board.D12) #initialize bus
display_bus = displayio.FourWire(spi, command=dc, chip_select=cs, reset=reset, baudrate=230400) # 1000000
#SDA IO45
#SCK IO46

# Create the display object
display = adafruit_displayio_ssd1306.SSD1306(display_bus, width=128, height=64)

splash = displayio.Group() #Manage a group of sprites and groups and how they are inter-related.
display.show(splash)

# Create a bitmap where we can draw pixels
bitmap = displayio.Bitmap(128, 64, 2)  # 128x64 pixels, 2 colors (black and white)
palette = displayio.Palette(2)
palette[0] = 0x000000  # Black
palette[1] = 0xFFFFFF  # White

# Create a TileGrid to hold the bitmap
tile_grid = displayio.TileGrid(bitmap, pixel_shader=palette)

# Create a Group and add the TileGrid to it
group = displayio.Group()
group.append(tile_grid) # append() adds elements to splash and make them visible

# Show the group on the display 
display.show(group)

def drawPixel(x, y, z):
    if 0 <= x < 128 and 0 <= y < 64:  # will only draw pixels within bounds
        if bitmap[x,y] != int(z):
            bitmap[x, y] = int(z)

def drawCar():
    global scaleDown
    carPixels = set()
    height = 58 # y coord 

# real distance in mm / scaleDown = pixelPlot
# 8000/10 = 800 (too far at this scaleDown value)
# 8000/x = 440 (find x for it to be at the midpoint) (x = 18.18)
# 8000/100 = 80 ( < 127, will fit on screen)

# 2000/10 = 200
# 2000/18.18 = 110
# 2000/100 = 20

# 1000/10 = 100 
# 1000/18.18 = 55
# 1000/100 = 10 

    if scaleDown == scdh:
        for i in range(57,69): # bumper width
            carPixels.add((i,height)) # bumper height
        for i in range(height + 1,64): # left side height
            carPixels.add((56,i)) # left side x coord
        for i in range(height + 1,64): # right side height
            carPixels.add((69,i)) # right side x coord

    elif scaleDown == scdm:
        # 28
        carPixels.add((28,height+5))
        carPixels.add((29,height+4))
        carPixels.add((29,height+3))
        for i in range(30,32):
            carPixels.add((i,height+2)) 
        for i in range(32,50):
            carPixels.add((i,height+1)) 
        for i in range(50,77): # bumper width
            carPixels.add((i,height)) # bumper height
        for i in range(77,95): # bumper width
            carPixels.add((i,height+1)) # bumper height
        for i in range(95,97):
            carPixels.add((i,height+2))
        carPixels.add((97,height+3))
        carPixels.add((97,height+4))
        carPixels.add((98,height+5))
        
    elif scaleDown == scdl:
        for i in range(57,69): # bumper width
            carPixels.add((i,height)) # bumper height
        for i in range(height + 1,64): # left side height
            carPixels.add((56,i)) # left side x coord
        for i in range(height + 1,64): # right side height
            carPixels.add((69,i)) # right side x coord
        for i in range(59,67):
            carPixels.add((i,63))

        # carPixels.add((63,height+5))
        # 98

    for x in carPixels:
        bitmap[x] = 1
drawCar()
# 0 - 57 is the y range because the car bumper goes to y = 58 - 63

def clearScreen():
    global timeSinceReset
    bitmap.fill(0)
    drawCar()
    timeSinceReset = time.monotonic()

timeSinceReset = time.monotonic()

# Function to update plot based on angle and distance
def updatePlot(i):
    curTime = time.monotonic()
    global timeSinceReset, scaleDown
    
    if (27000 <= i[1] <= 36000) or (0 <= i[1] <= 9000):
        # Get the angle and distance from the data
        angle = ( 9000 - i[1]) / 100.0  # Convert angle from scaled value (e.g., 9000 = 90Â°) to degrees
        distance = i[0]  # Distance value
        
        # Convert angle to radians (since math functions use radians)
        angle_radians = math.radians(angle)

        # Center of the screen
        xMid = 63
        yMid = 59  # center the LiDAR to the car on the screen

        # polar to cartesian conversion
        x = xMid + int(distance * math.cos(angle_radians) / scaleDown)
        y = yMid - int(distance * math.sin(angle_radians) / scaleDown)  # Invert Y-axis



        drawPixel(x,y,1)  # Run the expression for each (x, y) pair
        if (curTime - timeSinceReset >= refreshRate):
            clearScreen()
#-------------------------------------------------------------------------
#Receiver Wireless Code Start
#import espnow, time

e = espnow.ESPNow()
packets = []
print("Initializing ESP-NOW Receiver...")
while True:
    # Read any incoming message
    if e:
        message = e.read()
        #print(type(message))
        #print("Received message:", message.msg)
        decoded_data = message.msg.decode('utf-8')  # Decode from bytes to string
        original_element = json.loads(decoded_data)  # Deserialize the JSON string back to the original element
        if isinstance(original_element,list) and original_element[0] != 0 and original_element[1] != 0:
            updatePlot(original_element)


        # more efficient but too volatile
        # # print(original_element)
        # if isinstance(original_element,str) and len(original_element) == 120:
        #     # print(original_element) 
        #     for i in range(0, len(original_element), 10):
        #         num1 = int(original_element[i:i+5])
        #         num2 = int(original_element[i+5:i+10])
        #         updatePlot([num1, num2])


    # Add a small delay to avoid overwhelming the loop
    time.sleep(0.001)  # Adjust sleep time as needed
    if leftButton.value == False and pLeftButton == True: # scaleDown go up
        if scaleDown == scdl:
            scaleDown = scdm
        elif scaleDown == scdm:
            scaleDown = scdh
        clearScreen()
    if rightButton.value == False and pRightButton == True: # scaleDown go down 
        if scaleDown == scdm:
            scaleDown = scdl
        elif scaleDown == scdh:
            scaleDown = scdm
        clearScreen()
    pLeftButton = leftButton.value
    pRightButton = rightButton.value

#Receiver Wireless Code Ends
#-------------------------------------------------------------------------
#-------------------------------------------------------------------------
#-------------------------------------------------------------------------
#-------------------------------------------------------------------------
#-------------------------------------------------------------------------
#-------------------------------------------------------------------------


import board
import time
import random
import displayio
import adafruit_displayio_ssd1306
import busio
import espnow
import math
import json
from digitalio import DigitalInOut, Direction


# Release any previous display and initialize pins
displayio.release_displays()

WIDTH = 128
HEIGHT = 64
BORDER = 5

# Set up the SPI connection
cs = board.D26  # Chip select
dc = board.D27  # Data/Command
reset = board.D14  # Reset pin
spi = busio.SPI(board.D13, MOSI=board.D12)  # SPI bus initialization

display_bus = displayio.FourWire(spi, command=dc, chip_select=cs,
                                 reset=reset, baudrate=1000000)

# Create the display object
display = adafruit_displayio_ssd1306.SSD1306(display_bus, width=WIDTH, height=HEIGHT)

splash = displayio.Group()  # Create a group for managing display objects
display.root_group = splash  # Show the splash group on the display

# Create a bitmap and a palette for drawing
bitmap = displayio.Bitmap(128, 64, 2)  # 128x64 pixels, 2 colors (black and white)
palette = displayio.Palette(2)
palette[0] = 0x000000  # Black
palette[1] = 0xFFFFFF  # White

# Create a TileGrid to hold the bitmap and use the palette
tile_grid = displayio.TileGrid(bitmap, pixel_shader=palette)

# Create a new display group and add the tile grid to it
group = displayio.Group()
group.append(tile_grid)

# Set the root group to display the group on the screen
display.root_group = group

# Function to draw a single pixel on the display
def draw_pixel(x, y, color):
    if 0 <= x < 128 and 0 <= y < 64:  # Ensure the pixel is within bounds
        bitmap[x, y] = color
        time.sleep(0.1)

def turnoff_pixel(x, y):
    if 0 <= x < 128 and 0 <= y < 64:  # Ensure the pixel is within bounds
        bitmap[x, y] = 0

# Update loop for drawing pixels
while True:
    for x in range(128):
        draw_pixel(x, 0, 1)  # Draw a white pixel at (x, 0)
    time.sleep(0.1)
    for x in range(128):
        turnoff_pixel(x, 0)  # Turn off the pixel at (x, 0)
    time.sleep(0.1)


'''

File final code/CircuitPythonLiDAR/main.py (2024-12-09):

import board
import busio
import time
import math

# screen libraries
import displayio
import adafruit_displayio_ssd1306 

import espnow, time # type: ignore

import json # packing data to send wirelessly

from digitalio import DigitalInOut, Direction # troubleshooting LEDS

crashLED = DigitalInOut(board.IO18)
crashLED.direction = Direction.OUTPUT
crashLED.value = False

# =============================================================================================================================
# wireless communication initialization

e = espnow.ESPNow()
peer = espnow.Peer(b'\x48\xCA\x43\x5F\xAF\x90')
e.peers.append(peer)
print("Initializing ESP-NOW Sender...")
timeAtRun = time.monotonic()

# =============================================================================================================================
# display initialization

displayio.release_displays() #release pins

# Set up the SPI or I2C connection (depending on your setup)
cs = board.IO26 #IO26
dc = board.IO47 #IO47
reset = board.IO33 #IO33
spi = busio.SPI(board.IO46, MOSI=board.IO45) #initialize bus
display_bus = displayio.FourWire(spi, command=dc, chip_select=cs, reset=reset, baudrate=230400) # 1000000
#SDA IO45
#SCK IO46

# Create the display object
display = adafruit_displayio_ssd1306.SSD1306(display_bus, width=128, height=64)

splash = displayio.Group() #Manage a group of sprites and groups and how they are inter-related.
display.show(splash)

# Create a bitmap where we can draw pixels
bitmap = displayio.Bitmap(128, 64, 2)  # 128x64 pixels, 2 colors (black and white)
palette = displayio.Palette(2)
palette[0] = 0x000000  # Black
palette[1] = 0xFFFFFF  # White

# Create a TileGrid to hold the bitmap
tile_grid = displayio.TileGrid(bitmap, pixel_shader=palette)

# # Create a Group and add the TileGrid to it
group = displayio.Group()
group.append(tile_grid) # append() adds elements to splash and make them visible

# Show the group on the display 
display.show(group)

def drawPixel(x, y, z):
    if 0 <= x < 128 and 0 <= y < 64:  # will only draw pixels within bounds
        bitmap[x, y] = int(z)

def drawCar():
    carPixels = ((57,56),(58,56),(59,56),(60,56),(61,56),(62,56),(63,56),(64,56),(65,56),(66,56),(67,56),(68,56), # bumper
             (56,57),(56,58),(56,59),(56,60),(56,61),(56,62),(56,63),(69,57),(69,58),(69,59),(69,60),(69,61),(69,62),(69,63), # sides
             (60,62),(61,62),(62,62),(63,62),(64,62),(65,62),(59,63),(66,63),(57,57),(68,57)) # window
    for x in carPixels:
        bitmap[x] = 1
drawCar()

# 0 - 55 is the y range because the car bumper goes to y = 56 - 63

def clearScreen():
    bitmap.fill(0)

# 1d distance troubleshooting
lastX = None
lastY = None
timeSinceReset = time.monotonic()
timeSinceReset1 = time.monotonic()

# clearCounter = 0        # counts the amount of plotted pixels before clearing screen
timeConst = 2000          # value clearCounter needs to surpass to clear screen

# Function to update plot based on angle and distance
def updatePlot(i):
    curTime = time.monotonic()
    global timeSinceReset
    printSet = set()
    
    if (27000 <= i[1] <= 36000) or (0 <= i[1] <= 9000):
        # Get the angle and distance from the data
        angle = ( 9000 - i[1]) / 100.0  # Convert angle from scaled value (e.g., 9000 = 90°) to degrees
        distance = i[0]  # Distance value
        
        # Convert angle to radians (since math functions use radians)
        angle_radians = math.radians(angle)

        # Center of the screen
        xMid = 63
        yMid = 55  # center the LiDAR to the car on the screen

        scaleDown = 5 # variable to adjust to zoom in or out on the screen

        # polar to cartesian conversion
        x = xMid + int(distance * math.cos(angle_radians) / scaleDown)
        y = yMid - int(distance * math.sin(angle_radians) / scaleDown)  # Invert Y-axisnnnnnnnnnnnnnnnn



#        drawPixel(x,y,1)  # Run the expression for each (x, y) pair
        if (curTime - timeSinceReset >= 1):
#            clearScreen()
#            drawCar()
            timeSinceReset = time.monotonic()
            e.send(b'ojsdfjh')

# =============================================================================================================================
# LiDAR sensor initialization

# Create a UART object using busio; timeout is the amount of time it will wait to take in info
uart = busio.UART(board.TX, board.RX, baudrate=230400, timeout=0.01)

# Buffer to hold a single packet of data (47 bytes)
packet_size = 47
packet = []

sampledData = [0] * 12

prevData = 0

import espidf

# main function =============================================
while True:
    # time.sleep(1)
    # print('saoidfo')


    # intake lidar data
    # =============================================================================================================================

    if uart.in_waiting > 0:
        # 'data' holds however many bytes that are waiting in the "buffer" memory, adds it to 'packet'
        data = uart.read(uart.in_waiting)
        packet.extend(data)

        while len(packet) >= packet_size:
            # Extract the first 47 bytes from the packet buffer
            curPack = packet[:packet_size]
            packet = packet[packet_size:]  # Remove processed bytes from the packet buffer

            # Check start byte
            if curPack[0] == 0x54:
                # current
                # print("radar speed:", end = " ")
                # print(curPack[3]*256 + curPack[2])

                startAngle = curPack[5]*256 + curPack[4]
                endAngle = curPack[43]*256 + curPack[42]

                totalAngle = endAngle - startAngle

                # inbetween packet data structure: 
                # dtype: [distance, angle, strength, time]
                # position of motor is when angle ~= 0 or 360

                #  [curPack[3*i+6] + 256*curPack[3*i+7] , (totalAngle*(i))//12 + startAngle , curPack[3*i+8] ,curPack[45]*256 + curPack[44]]

                for i in range(12): # 12 sets of 3 starting at index 6 (dLSB, dMSB, sig)
                    distToAngle = (totalAngle*(i))//12 + startAngle
                    if ((27000 <= distToAngle <= 36000) or (0 <= distToAngle <= 9000)):
                        sampledData[i] = [curPack[3*i+6] + 256*curPack[3*i+7] , distToAngle]
                    
                # print(sampledData)
                # longInt = ""
                # for sublist in sampledData:
                #     if isinstance(sublist, list):
                #         longInt += f"{sublist[0]:05d}{sublist[1]:05d}"
                # print(longInt)
                # print(len(longInt))
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

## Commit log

2024-10-28 Create Wireless connection between ESP32s.mov
2024-10-28 Create wireless tested.png
2024-10-28 Submitting PCB schematic + weekend progress
    [ece196LiDAR.kicad_pcb, ece196LiDAR.kicad_sch]
2024-10-30 PCB submission
    [ByronSlidesAreBad.csv, ece196LiDAR.kicad_sch, ece196LiDAR2.kicad_pcb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]
2024-10-31 Updated PCB
    [ByronSlidesAreBad.csv, PCB_BOM.csv, ece196LiDAR.kicad_pcb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]
2024-10-31 updated PCB again
    [ece196LiDAR2.kicad_pcb]
2024-10-31 connected 5v trace
    [ece196LiDAR2.kicad_pcb]
2024-12-03 demo videos
    First videos of the lidar working
